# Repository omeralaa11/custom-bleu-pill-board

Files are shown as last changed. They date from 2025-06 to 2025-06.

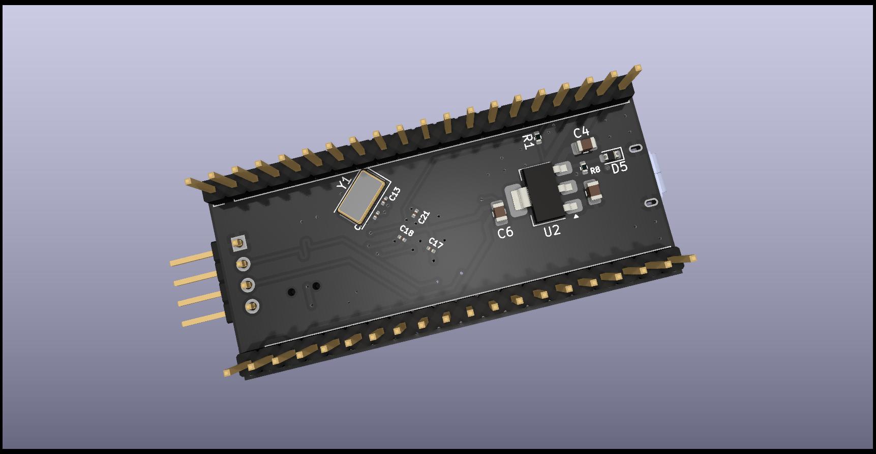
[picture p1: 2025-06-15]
STM32/3d images/stm320.jpg

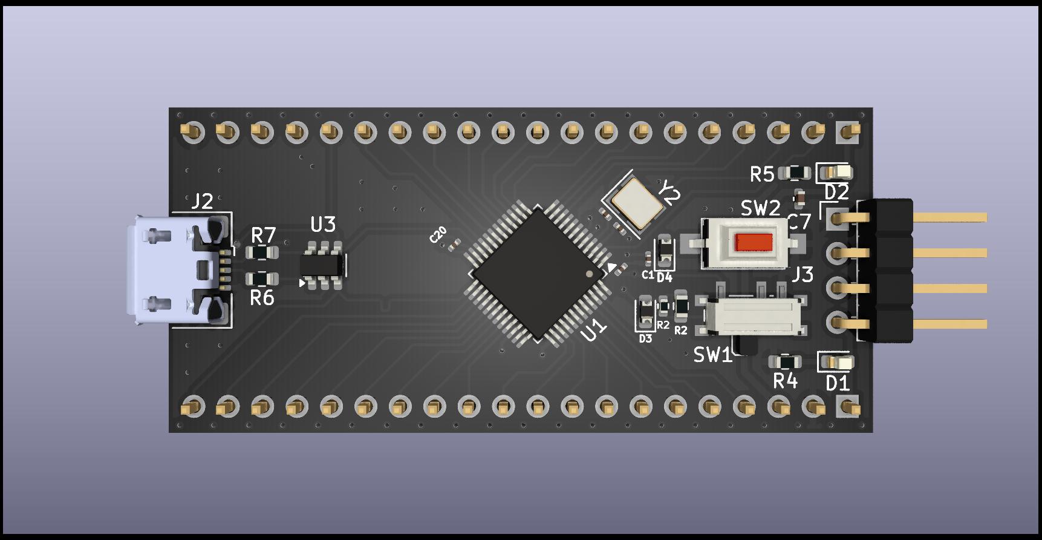
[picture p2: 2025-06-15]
STM32/3d images/stm32.jpg

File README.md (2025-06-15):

# Custom Blue Pill Board

This project is a custom-designed version of the popular Blue Pill development board based on the STM32F103C8T6 microcontroller. The design aims to provide a compact, reliable, and easily manufacturable board for embedded systems projects and educational use.

## 🚀 Objective

Redesign the STM32 Blue Pill board to:

- Improve component layout and manufacturability
- Remove unnecessary components for simplicity
- Ensure full compatibility with STM32 development tools and bootloaders

## 📦 Features

- **Microcontroller**: STM32F103C8T6 (ARM Cortex-M3, 72 MHz, 64KB Flash, 20KB RAM)
- **Power Input Options**: USB or external 5V
- **Reset & Boot Buttons**: Onboard tactile switches
- **Debugging**: SWD header for programming and debugging
- **LEDs**: Power and user LEDs for basic feedback
- **Crystal**: 8 MHz external crystal oscillator
- **Compact Form Factor**: Optimized layout for smaller size

## 🛠️ Tools Used

- **EDA Software**: KiCad 9
- **Microcontroller**: STM32F103C8T6
- **Programming**: STM32CubeIDE / STM32CubeProgrammer / PlatformIO

## ✅ Status

- ✅ Schematic Complete
- ✅ PCB Layout Finalized
- ✅ Gerbers Generated
- ⬜️ PCB Assembled and Tested *(Update this once tested)*

## 📌 Future Improvements

- Add reverse-current protection
- Consider support for higher-pin STM32 variants
- Add footprint for optional external Flash/EEPROM

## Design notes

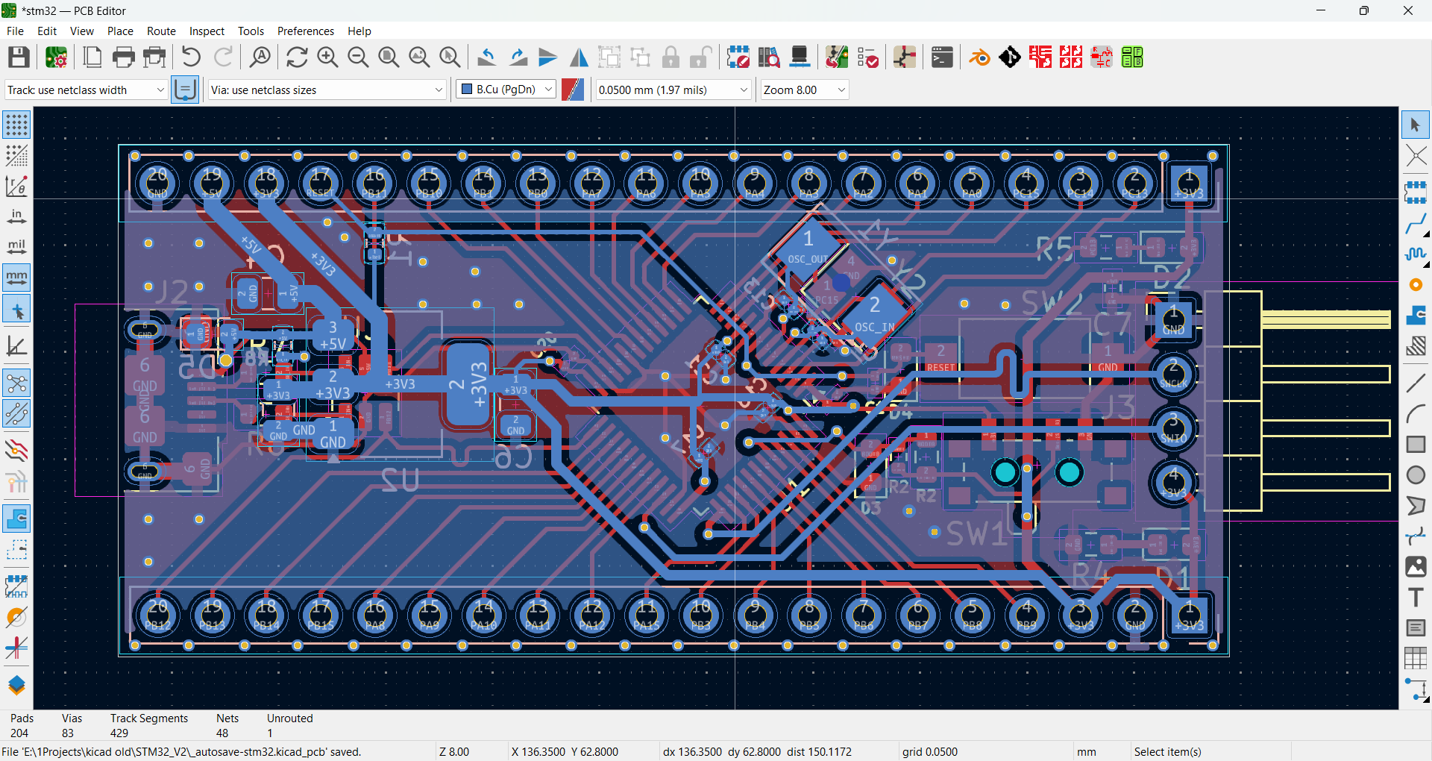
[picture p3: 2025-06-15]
STM32/3d images/Screenshot 2025-06-15 135336.png

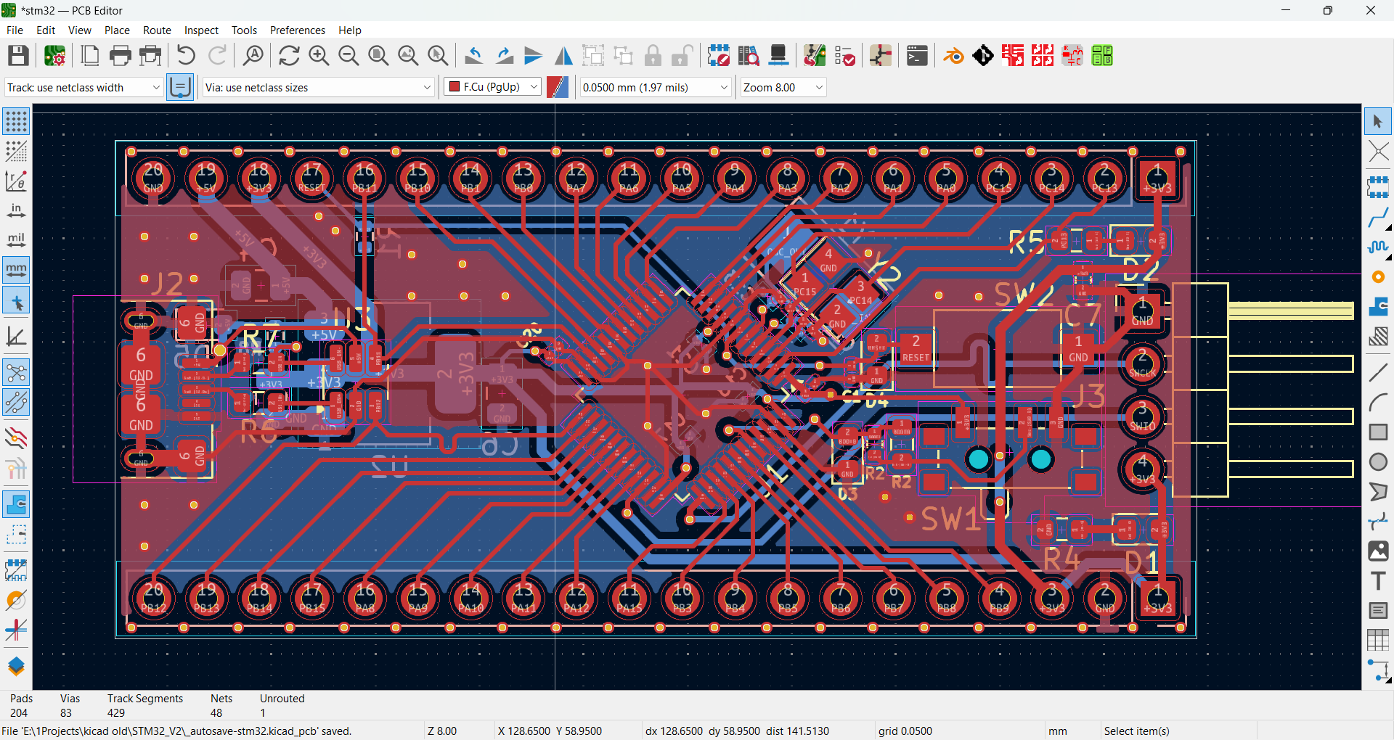
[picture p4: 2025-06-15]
STM32/3d images/Screenshot 2025-06-15 135351.png

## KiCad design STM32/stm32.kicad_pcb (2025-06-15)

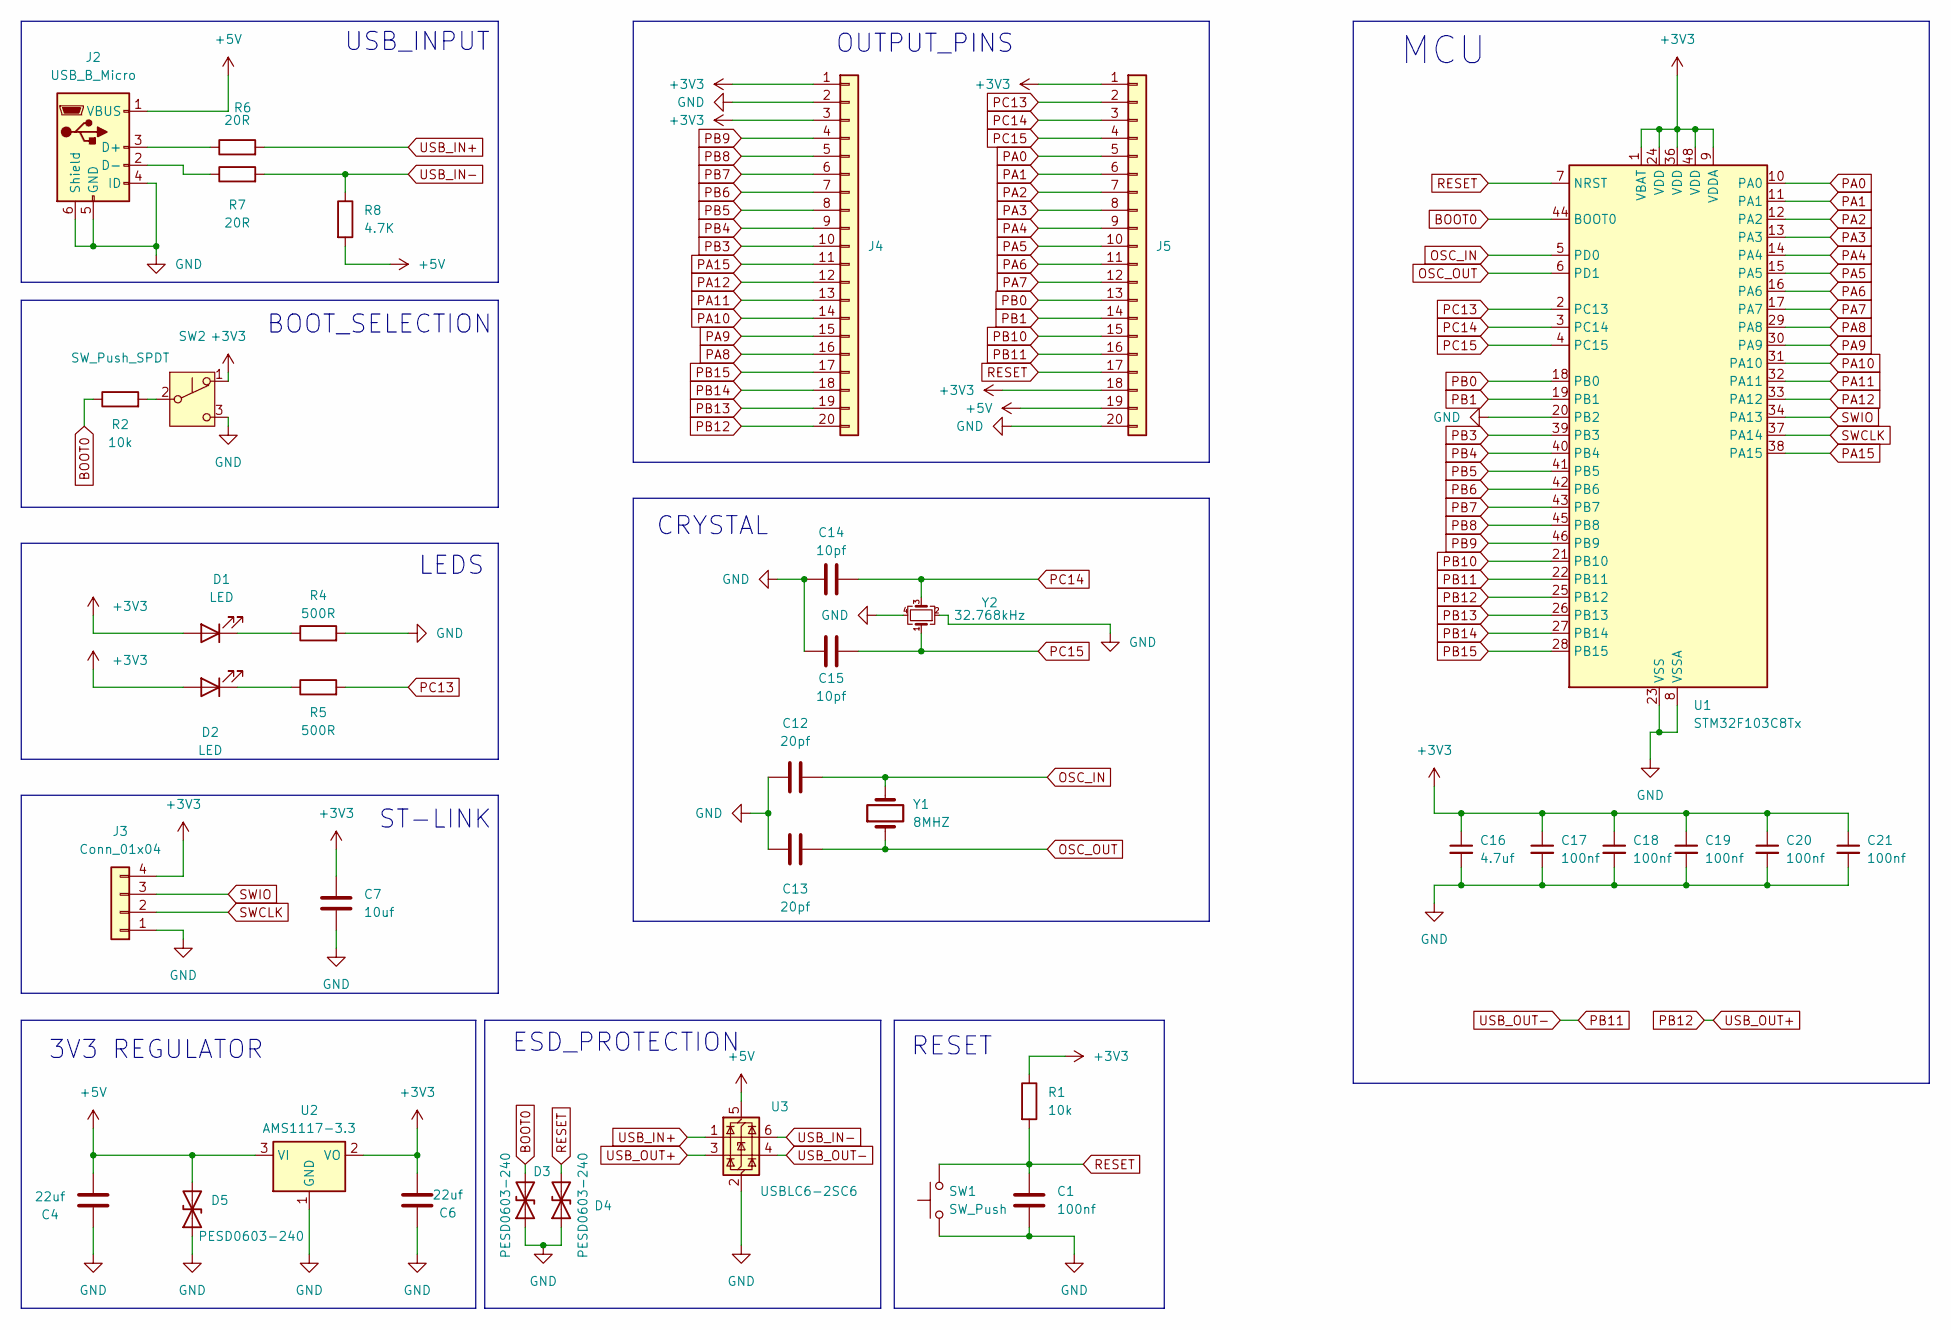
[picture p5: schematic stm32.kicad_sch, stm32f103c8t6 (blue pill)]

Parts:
C1, C17, C18, C19, C20, C21: 100nf; C_0201_0603Metric
C4, C6: 22uf; C_0805_2012Metric
C7: 10uf; C_0402_1005Metric
C12, C13: 20pf; C_0201_0603Metric
C14, C15: 10pf; C_0201_0603Metric
C16: 4.7uf; C_0805_2012Metric
D1, D2: LED; LED_0603_1608Metric
D3, D4, D5: PESD0603-240; D_0603_1608Metric
J2: USB_B_Micro; USB_Micro-B_Amphenol_10118193-0001LF_Horizontal
J3: Conn_01x04; PinHeader_1x04_P2.54mm_Horizontal
J4, J5: Conn_01x20; PinHeader_1x20_P2.54mm_Vertical
R1, R2: 10k; R_0402_1005Metric
R4, R5: 500R; R_0603_1608Metric
R6, R7: 20R; R_0603_1608Metric
R8: 4.7K; R_0402_1005Metric
SW1: SW_Push; SW_SPST_CK_RS282G05A3
SW2: SW_Push_SPDT; SW_SPDT_PCM12
U1: STM32F103C8Tx; LQFP-48_7x7mm_P0.5mm
U2: AMS1117-3.3; SOT-223-3_TabPin2
U3: USBLC6-2SC6; SOT-23-6
Y1: 8MHZ; Crystal_SMD_0603-2Pin_6.0x3.5mm
Y2: 32.768kHz; Crystal_SMD_SeikoEpson_FA238-4Pin_3.2x2.5mm

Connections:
+3V3: C6.1, C7.1, C16.1, C17.1, C18.1, C19.1, C20.1, C21.1, D1.2 (A), D2.2 (A), J3.4, J4.1, J4.3, J5.1, J5.18, R1.1, SW2.1 (A), U1.1 (VBAT), U1.9 (VDDA), U1.24 (VDD), U1.36 (VDD), U1.48 (VDD), U2.2 (VO)
+5V: C4.1, D5.2 (A2), J2.1 (VBUS), J5.19, R8.2, U2.3 (VI), U3.5 (VBUS)
BOOT0: D3.2 (A2), R2.1, U1.44 (BOOT0); also elsewhere on the board
GND: C1.2, C4.2, C6.2, C7.2, C12.1, C13.1, C14.1, C15.1, C16.2, C17.2, C18.2, C19.2, C20.2, C21.2, D3.1 (A1), D4.1 (A1), D5.1 (A1), J2.4 (ID), J2.5 (GND), J2.6 (Shield), J3.1, J4.2, J5.20, R4.2, SW1.1, SW2.3 (C), U1.8 (VSSA), U1.20 (PB2), U1.23 (VSS), U1.35 (VSS), U1.47 (VSS), U2.1 (GND), U3.2 (GND), Y2.2, Y2.4
unnamed: D1.1 (K), R4.1
unnamed: D2.1 (K), R5.1
unnamed: J2.3 (D+), R6.1
unnamed: J2.2 (D-), R7.1
unnamed 8: R2.2, SW2.2 (B); also elsewhere on the board
OSC_IN: C12.2, U1.5 (PD0), Y1.2
OSC_OUT: C13.2, U1.6 (PD1), Y1.1
PA0: J5.5, U1.10 (PA0)
PA1: J5.6, U1.11 (PA1)
PA2: J5.7, U1.12 (PA2)
PA3: J5.8, U1.13 (PA3)
PA4: J5.9, U1.14 (PA4)
PA5: J5.10, U1.15 (PA5)
PA6: J5.11, U1.16 (PA6)
PA7: J5.12, U1.17 (PA7)
PA8: J4.16, U1.29 (PA8)
PA9: J4.15, U1.30 (PA9)
PA10: J4.14, U1.31 (PA10)
PA11: J4.13, U1.32 (PA11)
PA12: J4.12, U1.33 (PA12)
PA15: J4.11, U1.38 (PA15)
PB0: J5.13, U1.18 (PB0)
PB1: J5.14, U1.19 (PB1)
PB3: J4.10, U1.39 (PB3)
PB4: J4.9, U1.40 (PB4)
PB5: J4.8, U1.41 (PB5)
PB6: J4.7, U1.42 (PB6)
PB7: J4.6, U1.43 (PB7)
PB8: J4.5, U1.45 (PB8)
PB9: J4.4, U1.46 (PB9)
PB10: J5.15, U1.21 (PB10)
PB11: J5.16, U1.22 (PB11), U3.4 (I/O2)
PB12: J4.20, U1.25 (PB12), U3.3 (I/O2)
PB13: J4.19, U1.26 (PB13)
PB14: J4.18, U1.27 (PB14)
PB15: J4.17, U1.28 (PB15)
PC13: J5.2, R5.2, U1.2 (PC13)
PC14: C14.2, J5.3, U1.3 (PC14), Y2.3
PC15: C15.2, J5.4, U1.4 (PC15), Y2.1
RESET: C1.1, D4.2 (A2), J5.17, R1.2, SW1.2, U1.7 (NRST)
SWCLK: J3.2, U1.37 (PA14)
SWIO: J3.3, U1.34 (PA13)
USB_IN+: R6.2, U3.1 (I/O1)
USB_IN-: R7.2, R8.1, U3.6 (I/O1)

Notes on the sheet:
CRYSTAL
ST-LINK
RESET
ESD_PROTECTION
USB_INPUT
BOOT_SELECTION
MCU
LEDS
OUTPUT_PINS
3V3 REGULATOR

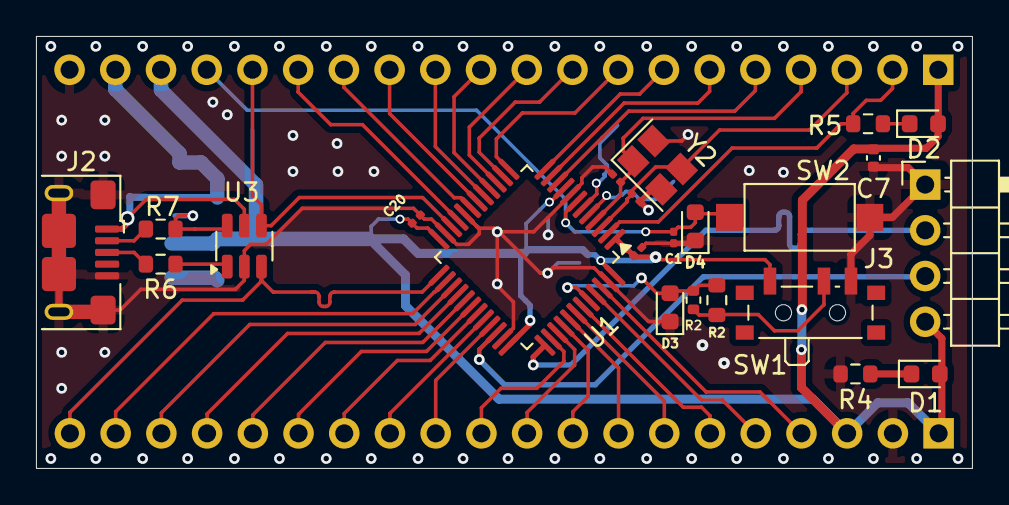
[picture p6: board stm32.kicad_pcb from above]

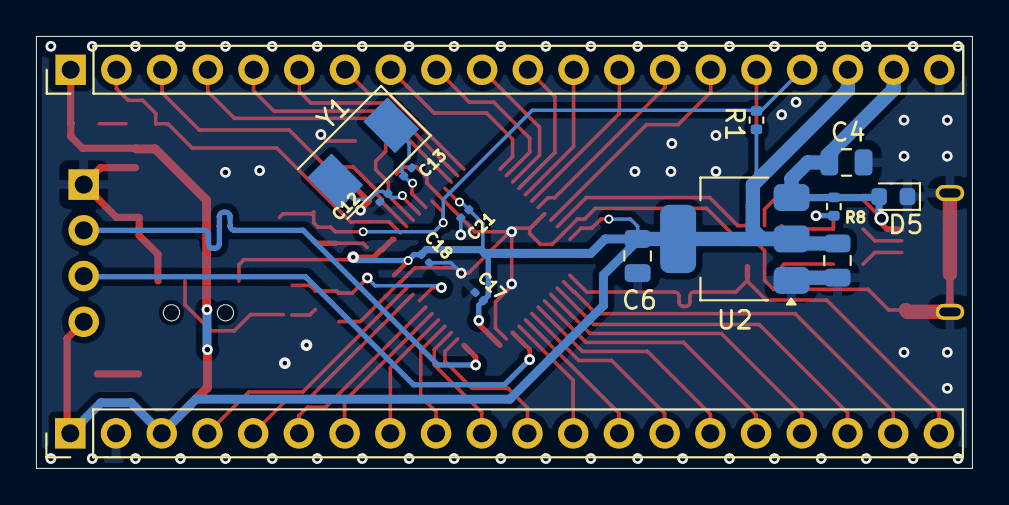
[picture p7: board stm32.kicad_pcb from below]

Board: 2 copper layers, 52.0 x 24.0 mm, 38 parts (15 on the bottom side), 48 nets.

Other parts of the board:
R2#2: 10k; R_0402_1005Metric

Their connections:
BOOT0: R2#2.1; also elsewhere on the board
unnamed 8: R2#2.2; also elsewhere on the board
